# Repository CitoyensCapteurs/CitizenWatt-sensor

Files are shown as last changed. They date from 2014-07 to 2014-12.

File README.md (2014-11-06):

CitizenWatt-sensor
==================
Hardware and code running on the sensor for the CitizenWatt project.

For the sensor, install some libs first :
- RF24: https://github.com/stanleyseow/RF24/tree/2a1a4e6e27056844a3bc419d65b8a2d4e0f1770e
- EmonLib: https://github.com/openenergymonitor/EmonLib
- AESLib: https://github.com/DavyLandman/AESLib

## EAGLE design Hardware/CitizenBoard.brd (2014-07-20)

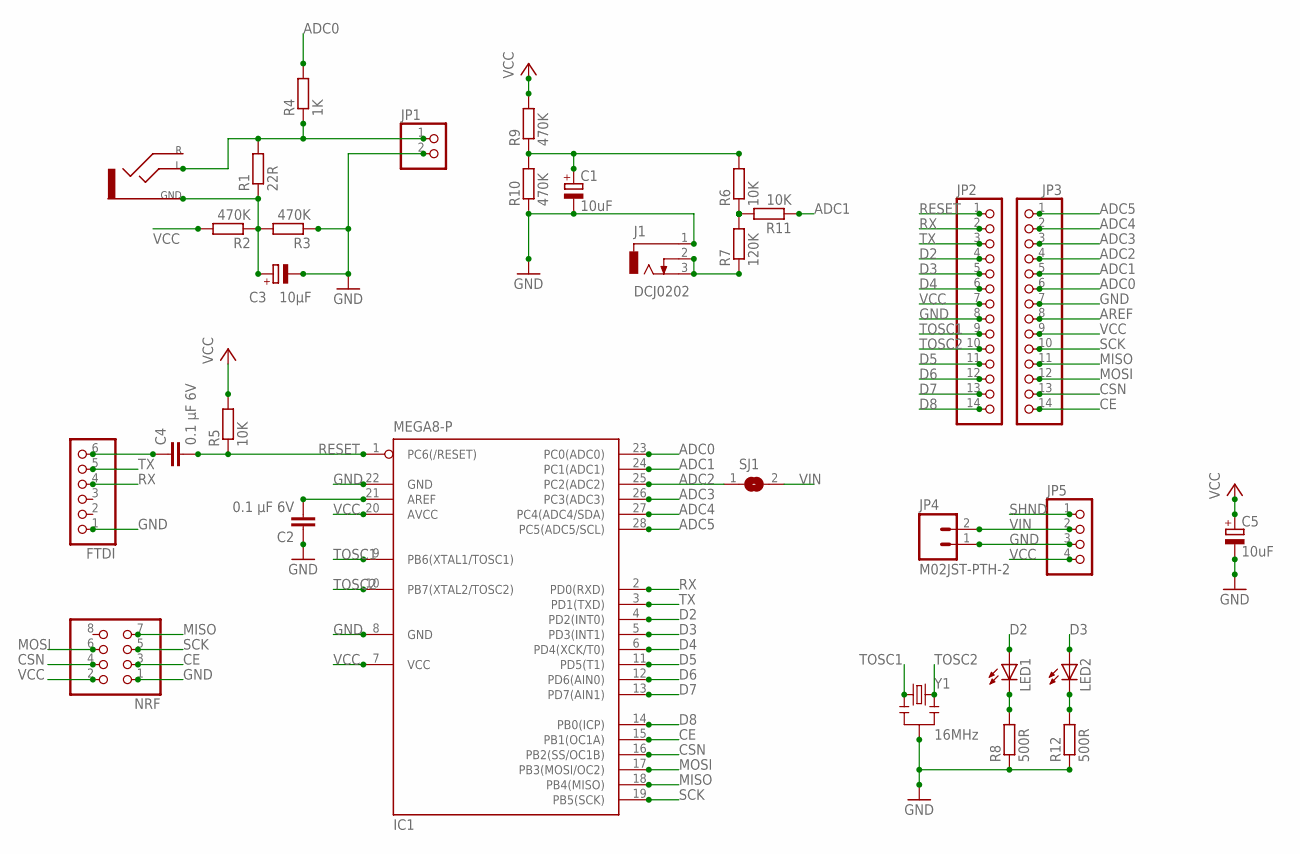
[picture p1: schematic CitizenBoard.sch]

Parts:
C1, C5: 10uF; E2,5-6E
C2, C4: 0.1 µF 6V; C025-024X044
C3: 10µF; E2,5-6E
FTDI: PINHD-1X6; 1X06
IC1: MEGA8-P; DIL28-3
J1: DCJ0202
J2: AUDIO-JACK-3.5
JP1: PINHD-1X2; 1X02
JP2, JP3: PINHD-1X14; 1X14
JP4: M02JST-PTH-2; JST-2-PTH
JP5: PINHD-1X4; 1X04
LED1, LED2: LED3MM
NRF: PINHD-2X4; 2X04
R1: 22R; 0204/7
R2, R3, R9, R10: 470K; 0204/7
R4: 1K; 0204/7
R5, R6, R11: 10K; 0204/7
R7: 120K; 0204/7
R8, R12: 500R; 0204/7
SJ1: SJ
Y1: 16MHz; RESONATOR-PTH

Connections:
ADC0: IC1.23 (PC0(ADC0)), JP3.6, R4.2
ADC1: IC1.24 (PC1(ADC1)), JP3.5, R11.1
ADC2: IC1.25 (PC2(ADC2)), JP3.4, SJ1.1
ADC3: IC1.26 (PC3(ADC3)), JP3.3
ADC4: IC1.27 (PC4(ADC4/SDA)), JP3.2
ADC5: IC1.28 (PC5(ADC5/SCL)), JP3.1
AREF: C2.2, IC1.21 (AREF), JP3.8
CE: IC1.15 (PB1(OC1A)), JP3.14, NRF.3
CSN: IC1.16 (PB2(SS/OC1B)), JP3.13, NRF.4
D2: IC1.4 (PD2(INT0)), JP2.4, LED1.A
D3: IC1.5 (PD3(INT1)), JP2.5, LED2.A
D4: IC1.6 (PD4(XCK/T0)), JP2.6
D5: IC1.11 (PD5(T1)), JP2.11
D6: IC1.12 (PD6(AIN0)), JP2.12
D7: IC1.13 (PD7(AIN1)), JP2.13
D8: IC1.14 (PB0(ICP)), JP2.14
GND: C1.-, C2.1, C3.-, C5.-, FTDI.1, IC1.8 (GND), IC1.22 (GND), J1.1, JP1.2, JP2.8, JP3.7, JP4.1, JP5.3, NRF.1, R3.1, R8.1, R10.1, R12.1, Y1.2
MISO: IC1.18 (PB4(MISO)), JP3.11, NRF.7
MOSI: IC1.17 (PB3(MOSI/OC2)), JP3.12, NRF.6
N: J2.5T (L), JP1.1, R1.2, R4.1
unnamed: R6.1, R7.2, R11.2
unnamed: LED2.K (C), R12.2
unnamed: C4.1, FTDI.6
unnamed: C3.+, J2.1S (GND), R1.1, R2.1, R3.2
unnamed: LED1.K (C), R8.2
unnamed: J1.2, J1.3, R7.1
unnamed: C1.+, R6.2, R9.1, R10.2
RESET: C4.2, IC1.1 (PC6(/RESET)), JP2.1, R5.1
RX: FTDI.4, IC1.2 (PD0(RXD)), JP2.2
SCK: IC1.19 (PB5(SCK)), JP3.10, NRF.5
SHND: JP5.1
TOSC1: IC1.9 (PB6(XTAL1/TOSC1)), JP2.9, Y1.1
TOSC2: IC1.10 (PB7(XTAL2/TOSC2)), JP2.10, Y1.3
TX: FTDI.5, IC1.3 (PD1(TXD)), JP2.3
VCC: C5.+, IC1.7 (VCC), IC1.20 (AVCC), JP2.7, JP3.9, JP5.4, NRF.2, R2.2, R5.2, R9.2
VIN: JP4.2, JP5.2, SJ1.2

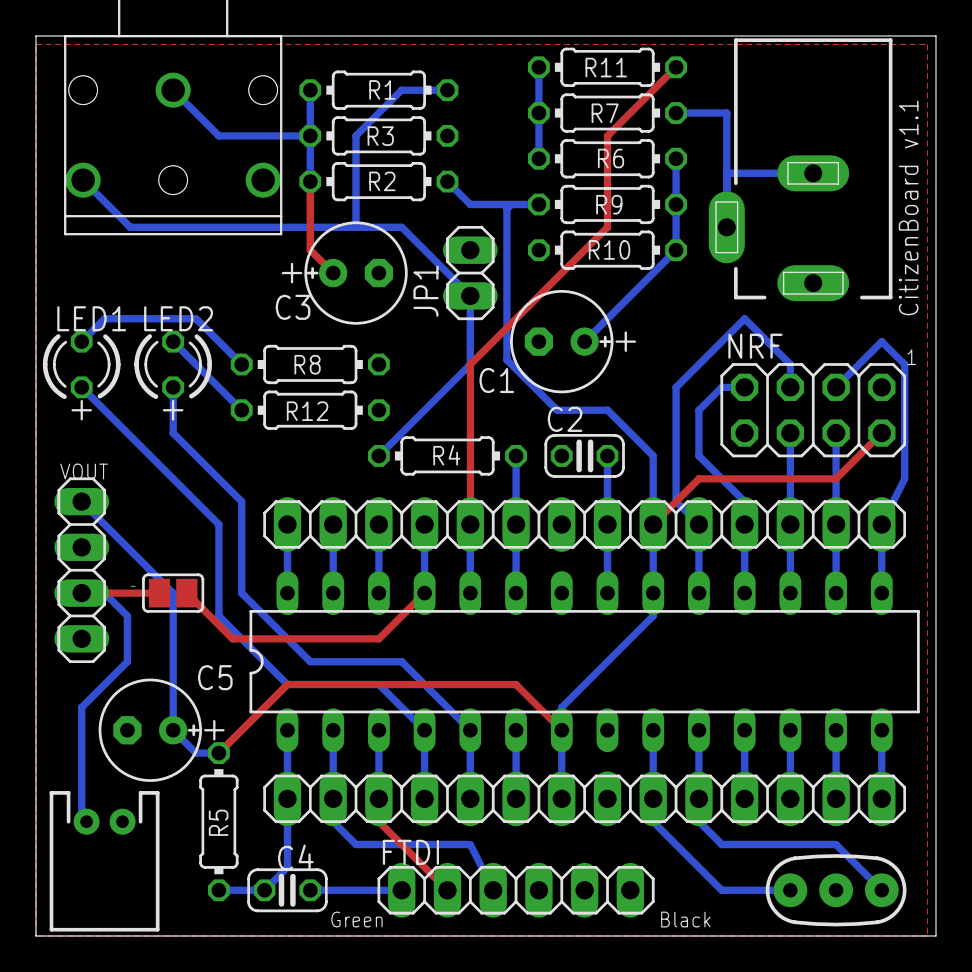
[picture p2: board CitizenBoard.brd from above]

Board: 2 copper layers, 50.0 x 50.0 mm, 31 parts (0 on the bottom side), 35 nets.

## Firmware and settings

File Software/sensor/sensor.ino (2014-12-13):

 ///////////////////
//   Includes    //
///////////////////

#include <EEPROM.h>
#include <SPI.h>
#include <avr/sleep.h>
#include <avr/power.h>
#include <nRF24L01.h>
#include <RF24.h>      // https://github.com/stanleyseow/RF24/tree/2a1a4e6e27056844a3bc419d65b8a2d4e0f1770e
#include "printf.h"
#include <EmonLib.h>   // https://github.com/openenergymonitor/EmonLib
#include <AESLib.h>    // https://github.com/DavyLandman/AESLib

///////////////////////
//   CONFIGURATION   //
///////////////////////

#define DEBUG 1
#define SERIAL_BAUDRATE 57600

// PreAmplifier level for the nRF
// Lower this to reduce power consumption. This will reduce range.
rf24_pa_dbm_e NRF_PA_LEVEL = RF24_PA_LOW;

// Radio pipe addresses for the 2 nodes to communicate.
uint64_t pipes[2] = { 0xE056D446D0LL, 0xF0F0F0F0D2LL };

// AES
uint8_t key[] = {0,1,2,3,4,5,6,7,8,9,10,11,12,13,14,15};

// Calibration factor for the intensity
double ICAL = 85.0;

// =============================================================

// Speed for the nrf module
// RF24_250KBPS / RF24_1MBPS / RF24_2MBPS
// Reduce it to improve reliability
rf24_datarate_e NRF_SPEED = RF24_250KBPS;

// Channel for the nrf module
// 76 is default safe channel in RF24
int NRF_CHANNEL = 0x4c;

// Set this to 0 to enable voltage measurement.
// Else, set this to your mean voltage.
double VOLTAGE = 240.0;

// Number of samples over which the mean must be done for the current measurement
int NUMBER_SAMPLES_I = 1480;

// Pin for current measurement
const int CURRENT_PIN = A0;

// Pin for voltage measurement
const int VOLTAGE_PIN = 0;

// Pin for the green LED
const int GREEN_LED_PIN = 2;

// Pin for the red LED
const int RED_LED_PIN = 3;

// Energy Monitor object
EnergyMonitor emon1;

///////////////////////
//   Declarations    //
///////////////////////

#define TIMEOUT 250 // timeout in ms

// Struct to send RF data
typedef struct {
    int power;
    int voltage;
    int battery;
    unsigned long timer;
    long padding4;
    int padding2;
} PayloadTX;

// Next measurement to be sent
PayloadTX nrf = {0, 0, 0, 0, 0, 0};

////////////////////////////////
//   Hardware configuration   //
////////////////////////////////

// Set up nRF24L01 radio on SPI bus plus pins 9 & 10
RF24 radio(9,10);

//////////////////////////////
//   Sleep configuration    //
//////////////////////////////

typedef enum { wdt_16ms = 0, wdt_32ms, wdt_64ms, wdt_128ms, wdt_250ms, wdt_500ms, wdt_1s, wdt_2s, wdt_4s, wdt_8s } wdt_prescalar_e;

void setup_watchdog(uint8_t prescalar);
void do_sleep(void);

//////////////////////////
//   Setup operation    //
//////////////////////////

void setup(void)
{
  pinMode(RED_LED_PIN, OUTPUT);
  pinMode(GREEN_LED_PIN, OUTPUT);
  digitalWrite(RED_LED_PIN, HIGH);
  digitalWrite(GREEN_LED_PIN, HIGH);
  
  
  Serial.begin(SERIAL_BAUDRATE);
  Serial.println(F("/!\\ STARTING CitizenWatt Sensor"));
  Serial.println(F("//////////////////////////////"));
  Serial.println(F("//    CitizenWatt sensor    //"));
  Serial.println(F("//    citizenwatt.paris     //"));
  Serial.println(F("////////////////////////////// \n"));

  if( DEBUG )
    printf_begin();

  //
  // Prepare sleep parameters
  //

  setup_watchdog(wdt_8s); // /!\ 8s sleeping

  //
  // Setup and configure rf radio
  //

  // Initialize nRF
  radio.begin();
  radio.setChannel(NRF_CHANNEL);

  // Max number of retries and max delay between them
  radio.setRetries(15, 15);

  // Reduce payload size to improve reliability
  radio.setPayloadSize(16);

  // Set the datarate
  radio.setDataRate(NRF_SPEED);

  // Use the largest CRC
  radio.setCRCLength(RF24_CRC_16);

  // Ensure auto ACK is enabled
  //radio.setAutoAck(1);

  // Use the adapted PA level
  radio.setPALevel(NRF_PA_LEVEL);

  // Open writing pipe
  radio.openWritingPipe(pipes[0]);
  radio.openReadingPipe(1, pipes[1]);

  if(DEBUG) {
    radio.printDetails();
  }
  
  // Init EnergyMonitor, with calibration factor for R1 = 22 Ohms
  emon1.current(0, ICAL);

  digitalWrite(RED_LED_PIN, LOW);
  digitalWrite(GREEN_LED_PIN, LOW);
}

///////////////////////////////
//   Loop part of the code   //
///////////////////////////////

void loop(void)
{
  //
  // Read Current
  //
  digitalWrite(GREEN_LED_PIN, HIGH);
  nrf.power = (int) (emon1.calcIrms(NUMBER_SAMPLES_I) * VOLTAGE);
  digitalWrite(GREEN_LED_PIN, LOW);
  
  // Set voltage
  nrf.voltage = VOLTAGE;
  
  // Read Vcc
  nrf.battery = (int) emon1.readVcc();
  
  // Adding random for AES
  nrf.timer = millis();
  
  if( DEBUG )
  {
    Serial.print("|");
    Serial.print(nrf.power);
    Serial.print("\t");
    Serial.print("|");
    Serial.print("\t");
    Serial.print(nrf.voltage);
    Serial.print("\t");
    Serial.print("|");
    Serial.print("\t");
    Serial.print(nrf.battery);
    Serial.print("\t");
    Serial.println("|");
    
    Serial.print(F("Clear :"));      
    PrintHex8((uint8_t*)&nrf, sizeof(PayloadTX));
    Serial.println();
    Serial.flush();
  }
  
  // AES ciphering
  aes128_enc_single(key, &nrf);
  
  if( DEBUG )
  {
    Serial.print(F("Cipher:"));      
    PrintHex8((uint8_t*)&nrf, sizeof(PayloadTX));
    Serial.println();
    Serial.flush();
  }
    
  //
  // Data sender
  //

  // First, stop listening so we can talk.
  radio.stopListening();
       
  radio.write(&nrf, sizeof(PayloadTX));

  // Now, continue listening now the goal is to get some data back as ACK
  radio.startListening();

  // Wait here until we get a response, or timeout (250ms)
  unsigned long started_waiting_at = millis();
  bool timeout = false;
  while ( ! radio.available() && ! timeout )
    if (millis() - started_waiting_at > TIMEOUT )
      timeout = true;

  // Describe the results
  if ( timeout && DEBUG )
    Serial.println(F("[!] Failed to send packet : response timed out ..."));
  
  // Stop listening
  radio.stopListening();
    
  //
  // Shut down the system
  //

  // 100ms for the MCU to settle 
  delay(100);

  // Power down the radio.  Note that the radio will get powered back up
  // on the next write() call.
  // TODO : Fix this !
  //radio.powerDown();

  // Sleep the MCU.  The watchdog timer will awaken in a short while, and
  // continue execution here.
  do_sleep();
  
  // 100ms for the MCU to settle 
  delay(100);
  
}

//////////////////////////
//   Sleep functions    //
//////////////////////////

// 0=16ms, 1=32ms,2=64ms,3=125ms,4=250ms,5=500ms
// 6=1 sec,7=2 sec, 8=4 sec, 9= 8sec

void setup_watchdog(uint8_t prescalar)
{
  prescalar = min(9,prescalar);
  uint8_t wdtcsr = prescalar & 7;
  if ( prescalar & 8 )
    wdtcsr |= _BV(WDP3);

  MCUSR &= ~_BV(WDRF);
  WDTCSR = _BV(WDCE) | _BV(WDE);
  WDTCSR = _BV(WDCE) | wdtcsr | _BV(WDIE);
}

ISR(WDT_vect)
{
}

void do_sleep(void)
{
  set_sleep_mode(SLEEP_MODE_PWR_DOWN); // sleep mode is set here
  sleep_enable();

  sleep_mode();                        // System sleeps here

  sleep_disable();                     // System continues execution here when watchdog timed out
}

// Function for debug
void PrintHex8(uint8_t *data, uint8_t length) // prints 8-bit data in hex with leading zeroes
{
  Serial.print("0x"); 
  for (int i=0; i<length; i++) { 
    if (data[i]<0x10) {Serial.print("0");} 
    Serial.print(data[i],HEX); 
    Serial.print(" "); 
  }
}

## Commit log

2014-05-11 Voltage measurement should be ok
    TODO : Intensity measurement + nRF sending
2014-05-12 nRF code should be there.
    TODO: power down + check readI code
2014-05-12 Code ok, powerdown resets…
    [sensor.ino]
2014-05-12 cast problem solved with dBm
    [sensor.ino]
2014-05-12 Some bugs left. Main code is here
    [sensor.ino]
2014-05-13 Base code for RaspberryPi
2014-05-15 eagle files
    [CitizenBoard V3.2.brd, CitizenBoard V3.2.sch]
2014-05-16 Board silk fix
    [CitizenBoard V3.2.brd, CitizenBoard V3.2.sch]
2014-05-18 Silk bottom
    [CitizenBoard V3.2.brd]
2014-05-19 Added TODO
    [CitizenBoard V3.2.brd, CitizenBoard V3.2.sch]
2014-05-20 v1.0 sent for printing, after minor update
    [CitizenBoard V3.2.brd, CitizenBoard V3.2.sch]
2014-06-28 Clement's code for the sensor
2014-06-28 Fix memory usage
    * Fix memory usage putting strings in flash memory
    * Small refactoring
    * Added automatic startup after 30s
    [sensor.ino]
2014-07-02 Révision du menu
    Le menu a été modifié
    Le chargement des paramètres également
    But : pouvoir mettre la valeur souhaitée, et non des paramètres
    prédéfinis
    Problème : plantages
2014-07-02 Fixed some bugs with serial baudrate overflow + declaration in switch
    [sensor.ino]
2014-07-02 Should be working, need to fix the sleep
    [sensor.ino]
2014-07-11 Renommage des fichiers
    [CitizenBoard.brd, CitizenBoard.sch]
2014-07-11 Divers corrections de placement
    Déplacement vers le haut de R1, R2, R3 et C3, pour les éloigner de R8.
    Marquage de la polarisation des diodes et des condensateurs sur le silk.
    Décalage du connecteur FTDI pour ne pas entrer en collision avec NRF
    Décalage de C1 pour la même raison
    [CitizenBoard.brd]
2014-07-11 Correction de l'empreinte du jack
    Et modification de tracés pour le champ de masse
    [CitizenBoard.brd, CitizenBoard.sch]
2014-07-20 Mesure de la valeur de la batterie
    via un solder pad
    [CitizenBoard.brd, CitizenBoard.sch]
2014-09-11 Add LED support
2014-09-15 LED Pin and sleep fix
    Red and green pin inverted
    Set the sleep (8 sec)
    Tried the battery measurement (failed)
    [sensor.ino]
2014-09-20 Sleep mode, NRF com and EmonLib
    Sleep mode is now working
    Now using EmonLib instead of a copy of their functions
    Serial Baudrate is now fixed to 57600
    Renamed nrf.intensity to nrf.power
    Battery monitoring is now working
    Improved NRF debug
    Known issue : Current RMS measuring is not working correctly
    [sensor.ino]
2014-09-22 Fix pin number
2014-12-13 Switched to 250K by default
    to improve reliability.

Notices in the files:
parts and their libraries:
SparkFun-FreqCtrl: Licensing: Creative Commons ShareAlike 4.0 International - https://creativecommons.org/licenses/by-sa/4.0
